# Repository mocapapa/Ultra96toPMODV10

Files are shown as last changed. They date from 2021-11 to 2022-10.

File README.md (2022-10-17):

# Ultra96toPMODV10

Gerber data and Pick&Place data for Ultra96toPMOD mezzanine board.

https://qiita.com/mocapapa/items/a2faa710503e4affa88b

- BokTech-Bom-Ultra96toPMODV10_minimum.xlsx ---- BOM file for BockTech
- Ultra96toPMODV10.brd ---- EAGLE layout data
- Ultra96toPMODV10.sch ---- EAGLE schematic data
- Ultra96toPMODV10_2021-10-22.zip ---- Gerber data
- Ultra96toPMODV10.mnt.zip ---- Pick & Place file for PCBA
- JLCPCB-PP-Ultra96toPMODV10_minimum.xlsx ---- Pick&Place file for JLCPCB
- JLCPCB-Bom-Ultra96toPMODV10_minimum.xlsx ---- BOM file for JLCPCB




JLCPCBのGerber Viewrにより作成
- 色変換 Top Solder Maskを0x00be00に(円形のため3回必要)
- 色変換 Holeを黒色に



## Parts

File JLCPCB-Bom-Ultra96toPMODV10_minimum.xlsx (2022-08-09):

Comment | Designator | Footprint | JLCPCB Part #
TXS0108EPWR | U1, U3 | TXS0108EPWR | C17206

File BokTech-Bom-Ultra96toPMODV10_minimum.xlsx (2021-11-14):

Item | Ref. | MPN | Digikey/Mouser PN | Quantity
1 | U1, U3 | TXS0108EPWR | 595-TXS0108EPWR | 2

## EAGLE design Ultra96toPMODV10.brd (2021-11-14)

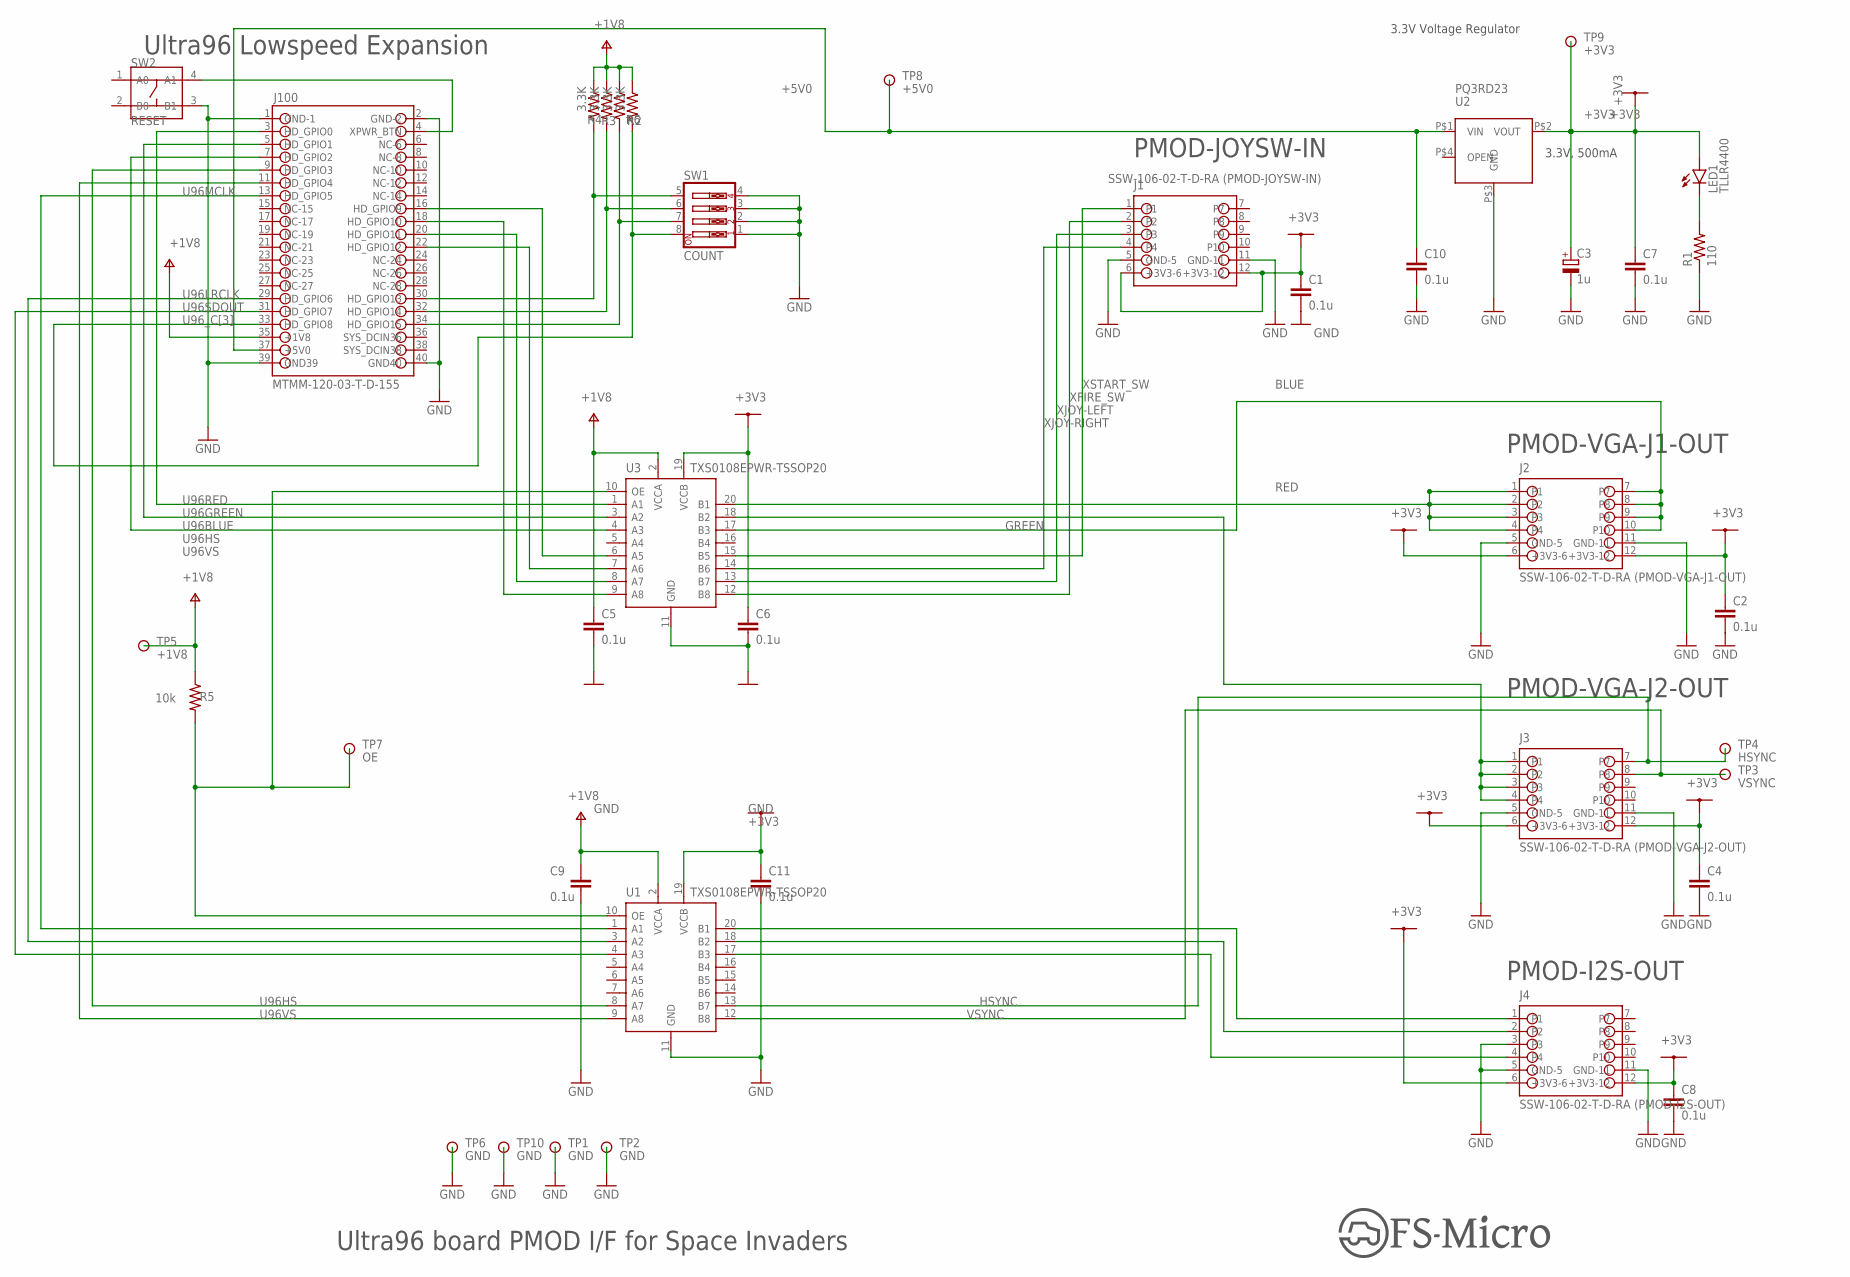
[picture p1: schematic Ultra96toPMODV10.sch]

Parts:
C1, C2, C4, C5, C6, C7, C8, C9, C10, C11: 0.1u; C050-025X075
C3: 1u; E2,5-5
J1: SSW-106-02-T-D-RA (PMOD-JOYSW-IN); SSW-106-02-T-D-RA
J2: SSW-106-02-T-D-RA (PMOD-VGA-J1-OUT); SSW-106-02-T-D-RA
J3: SSW-106-02-T-D-RA (PMOD-VGA-J2-OUT); SSW-106-02-T-D-RA
J4: SSW-106-02-T-D-RA (PMOD-I2S-OUT); SSW-106-02-T-D-RA
J100: MTMM-120-03-T-D-155
LED1: TLLR4400; LED3MM
R1: 110; 0207/10
R2, R3, R4, R6: 3.3K; 0207/10
R5: 10k; 0207/10
SW1: COUNT; EDG-04
SW2: RESET; SW4-6.0X6.0X5.0MM
TP1, TP2, TP6, TP10: GND; TP
TP3: VSYNC; TP
TP4: HSYNC; TP
TP5: +1V8; TP
TP7: OE; TP
TP8: +5V0; TP
TP9: +3V3; TP
U1, U3: TXS0108EPWR-TSSOP20; TSSOP20-0.65-6.5X4.4MM
U2: PQ3RD23

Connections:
+1V8: C5.1, C9.1, J100.35 (+1V8), R2.1, R3.1, R4.1, R5.1, R6.1, TP5.P$1, U1.2 (VCCA), U3.2 (VCCA)
+3V3: C1.1, C2.1, C3.+, C4.1, C6.1, C7.1, C8.1, C11.1, J1.6 (+3V3-6), J1.12 (+3V3-12), J2.6 (+3V3-6), J2.12 (+3V3-12), J3.6 (+3V3-6), J3.12 (+3V3-12), J4.6 (+3V3-6), J4.12 (+3V3-12), LED1.A, TP9.P$1, U1.19 (VCCB), U2.P$2 (VOUT), U3.19 (VCCB)
+5V0: C10.1, J100.37 (+5V0), TP8.P$1, U2.P$1 (VIN)
BLUE: J2.7, J2.8, J2.9, J2.10, U3.17 (B3)
GND: C1.2, C2.2, C3.-, C4.2, C5.2, C6.2, C7.2, C8.2, C9.2, C10.2, C11.2, J1.5 (GND-5), J1.11 (GND-11), J2.5 (GND-5), J2.11 (GND-11), J3.5 (GND-5), J3.11 (GND-11), J4.3, J4.5 (GND-5), J4.11 (GND-11), J100.1 (GND-1), J100.2 (GND-2), J100.39 (GND39), J100.40 (GND40), R1.1, SW1.1, SW1.2, SW1.3, SW1.4, SW2.3 (B1), TP1.P$1, TP2.P$1, TP6.P$1, TP10.P$1, U1.11 (GND), U2.P$3 (GND), U3.11 (GND)
GREEN: J3.1, J3.2, J3.3, J3.4, U3.18 (B2)
HSYNC: J3.7, TP4.P$1, U1.13 (B7)
LRCLK: J4.2, U1.18 (B2)
MCLK: J4.1, U1.20 (B1)
unnamed: LED1.K (C), R1.2
OE: R5.2, TP7.P$1, U1.10 (OE), U3.10 (OE)
RED: J2.1, J2.2, J2.3, J2.4, U3.20 (B1)
SDOUT: J4.4, U1.17 (B3)
U96BLUE: J100.7 (HD_GPIO2), U3.4 (A3)
U96GREEN: J100.5 (HD_GPIO1), U3.3 (A2)
U96HS: J100.9 (HD_GPIO3), U1.8 (A7)
U96LRCLK: J100.29 (HD_GPIO6), U1.3 (A2)
U96MCLK: J100.13 (HD_GPIO5), U1.1 (A1)
U96RED: J100.3 (HD_GPIO0), U3.1 (A1)
U96SDOUT: J100.31 (HD_GPIO7), U1.4 (A3)
U96VS: J100.11 (HD_GPIO4), U1.9 (A8)
U96_C[0]: J100.30 (HD_GPIO13), R4.2, SW1.5
U96_C[1]: J100.32 (HD_GPIO14), R3.2, SW1.6
U96_C[2]: J100.34 (HD_GPIO15), R2.2, SW1.7
U96_C[3]: J100.33 (HD_GPIO8), R6.2, SW1.8
U96_FIRE: J100.18 (HD_GPIO10), U3.9 (A8)
U96_LEFT: J100.20 (HD_GPIO11), U3.8 (A7)
U96_RIGHT: J100.22 (HD_GPIO12), U3.7 (A6)
U96_START: J100.16 (HD_GPIO9), U3.6 (A5)
VSYNC: J3.8, TP3.P$1, U1.12 (B8)
XFIRE_SW: J1.2, U3.12 (B8)
XJOY-LEFT: J1.3, U3.13 (B7)
XJOY-RIGHT: J1.4, U3.14 (B6)
XPWR_BTN: J100.4 (XPWR_BTN), SW2.4 (A1)
XSTART_SW: J1.1, U3.15 (B5)

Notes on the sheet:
PMOD-I2S-OUT
PMOD-VGA-J2-OUT
Ultra96 Lowspeed Expansion
3.3V Voltage Regulator
3.3V, 500mA
PMOD-VGA-J1-OUT
PMOD-JOYSW-IN
Ultra96 board PMOD I/F for Space Invaders

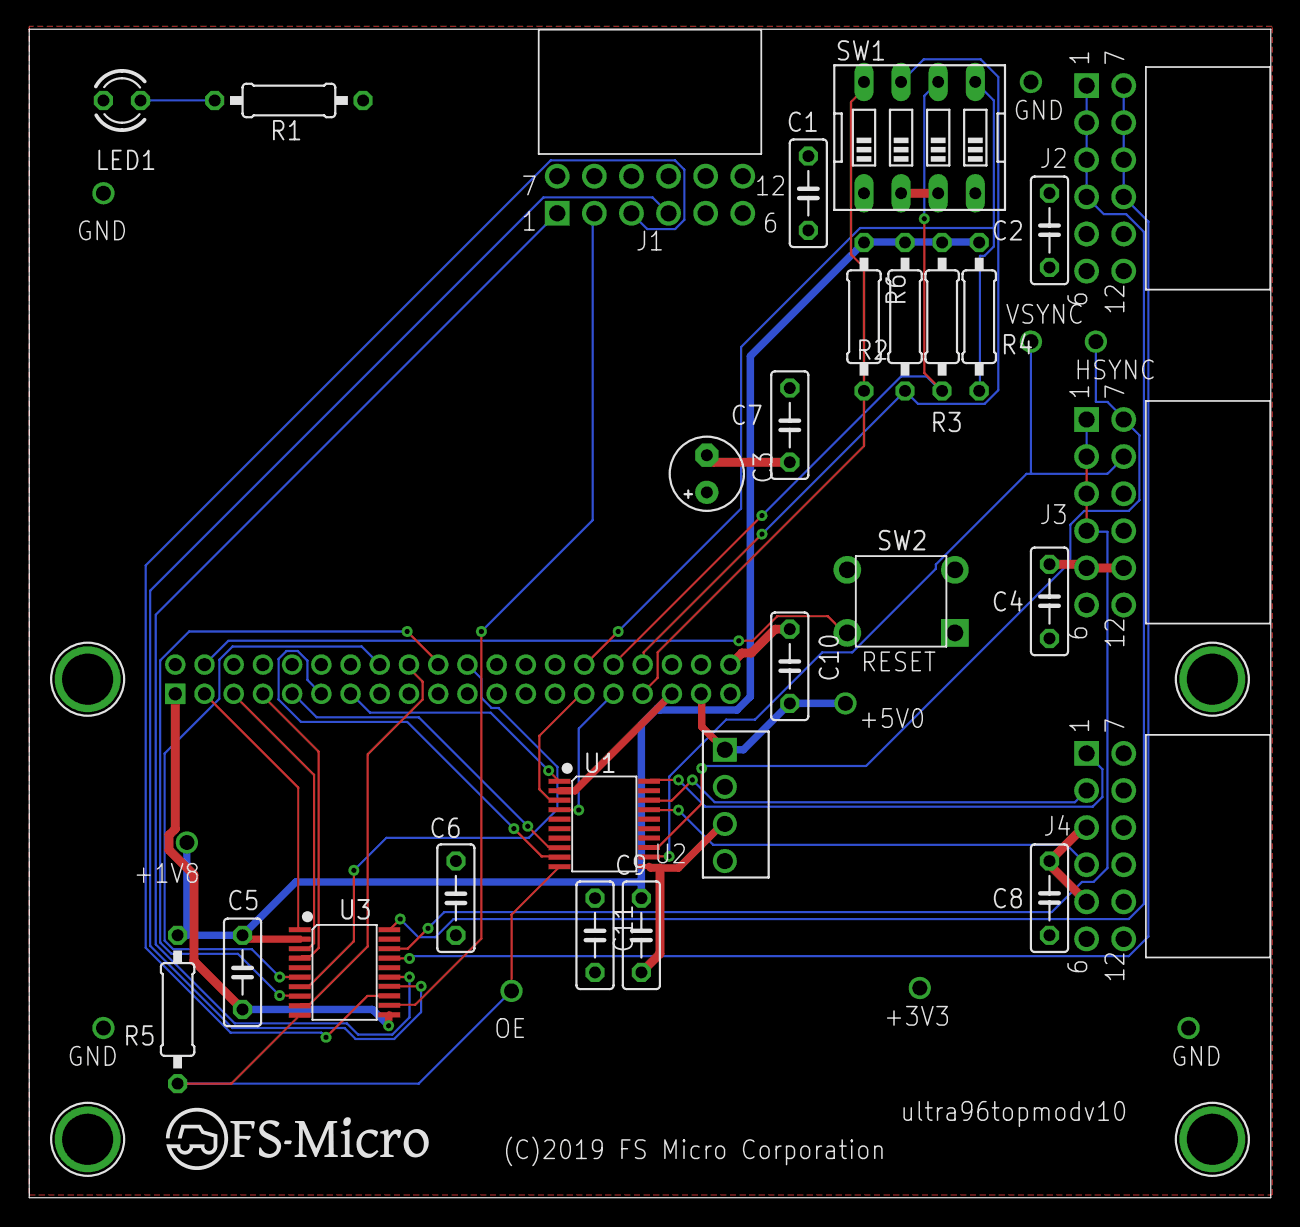
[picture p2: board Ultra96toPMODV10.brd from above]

Board: 2 copper layers, 85.0 x 80.0 mm, 41 parts (1 on the bottom side), 35 nets.

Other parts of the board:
U$1: REVERSELOGO
U$2: REVERSE_V10
U$3: SMALL-LOGO

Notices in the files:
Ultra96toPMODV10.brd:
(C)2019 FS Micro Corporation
